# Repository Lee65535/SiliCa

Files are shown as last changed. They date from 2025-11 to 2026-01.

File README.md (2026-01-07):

# SiliCa

`SiliCa` は、JIS X 6319-4（`FeliCa`）互換の非接触型 IC カードです。  
マイコンとして `ATtiny1616` を採用しており、外部電源を必要とせず、カードリーダからの給電によって動作します。

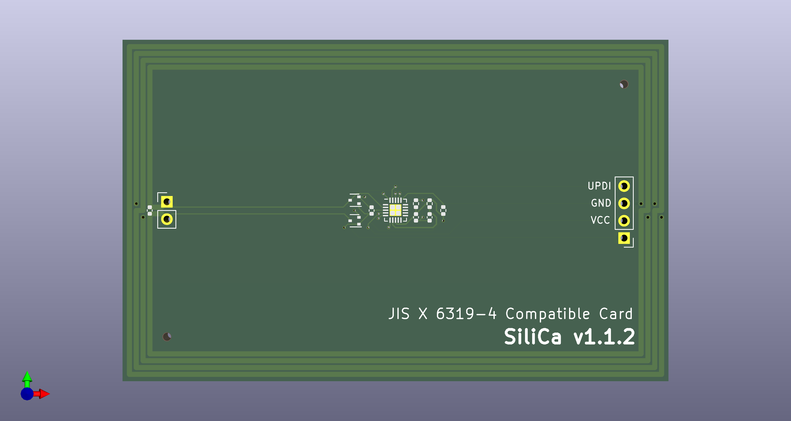
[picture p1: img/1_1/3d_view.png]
3D View


## About This Fork

This fork of SiliCa modifies the firmware so that the device can be used to emulate Amusement IC cards. It will work on bemani games and most bootleg / private servers for SEGA games, but due to technical limitations it is impossible to be used on legit SEGA arcades connected to official servers.

To emulate an Amusement IC, write the IDm as well as data in SPAD_0 to SiliCa, set the system code to 0x88B4, and set service codes to 0x0000 and 0x000B.

## 概要

`SiliCa` は、最小限のハードウェア構成で、 `FeliCa` プロトコルをファームウェアによって再現し、`FeliCa Standard` や `FeliCa Lite-S` のエミュレーションを実現することを目的としています。

また、`SiliCa` では、実際の `FeliCa` カードで書き換えが不可能な `IDm` やシステムコードなどのパラメータを自由に書き換えることができます。

詳細な仕様や使用方法については、寄稿した同人誌 `rand_r(&v3)` をご参照ください。

[技術書典マーケット](https://techbookfest.org/product/an6q3RzcSM0RcWQBevrEM9)
[BOOTH 紙版](https://unset-histfile.booth.pm/items/7650376)
[BOOTH 電子版](https://unset-histfile.booth.pm/items/7650390)

## 回路図

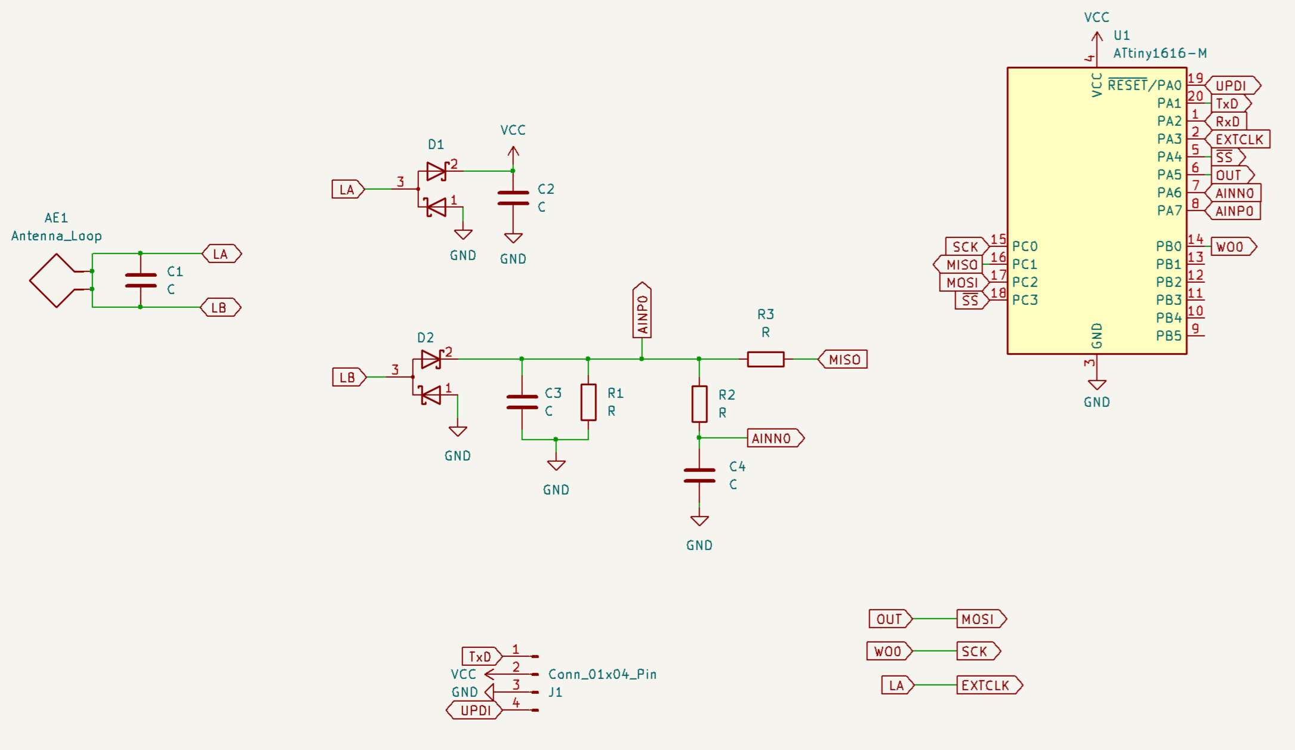
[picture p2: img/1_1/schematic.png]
Schematic


## 注意事項

本プロジェクトは、学術的および実験的な目的で提供されており、商業利用や実際の運用を目的としたものではありません。

---

```
FeliCaは、ソニー株式会社が開発した非接触ICカードの技術方式です。
FeliCaは、ソニーグループ株式会社の登録商標です。
本文では™、®は明記していません。
```

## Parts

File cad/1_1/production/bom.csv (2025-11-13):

Designator | Footprint | Quantity | Value | LCSC Part #
AE1 | PinHeader_1x02_P2.54mm_Vertical | 1 | Antenna_Loop
C1 | 0402 | 4 | C | C1567
C2 | 0402 | 4 | C | C15195
C3 | 0402 | 4 | C | C1523
C4 | 0402 | 4 | C | C1523
D1 | SOT-523 | 2 | D_Schottky_Dual_Series_AKC_Parallel | C2919808
D2 | SOT-523 | 2 | D_Schottky_Dual_Series_AKC_Parallel | C2919808
J1 | PinHeader_1x04_P2.54mm_Vertical | 1 | Conn_01x04_Pin
R1 | 0402 | 3 | R | C11702
R2 | 0402 | 3 | R | C11702
R3 | 0402 | 3 | R | C25123
U1 | VQFN-20-1EP_3x3mm_P0.4mm_EP1.7x1.7mm | 1 | ATtiny1616-M | C507118

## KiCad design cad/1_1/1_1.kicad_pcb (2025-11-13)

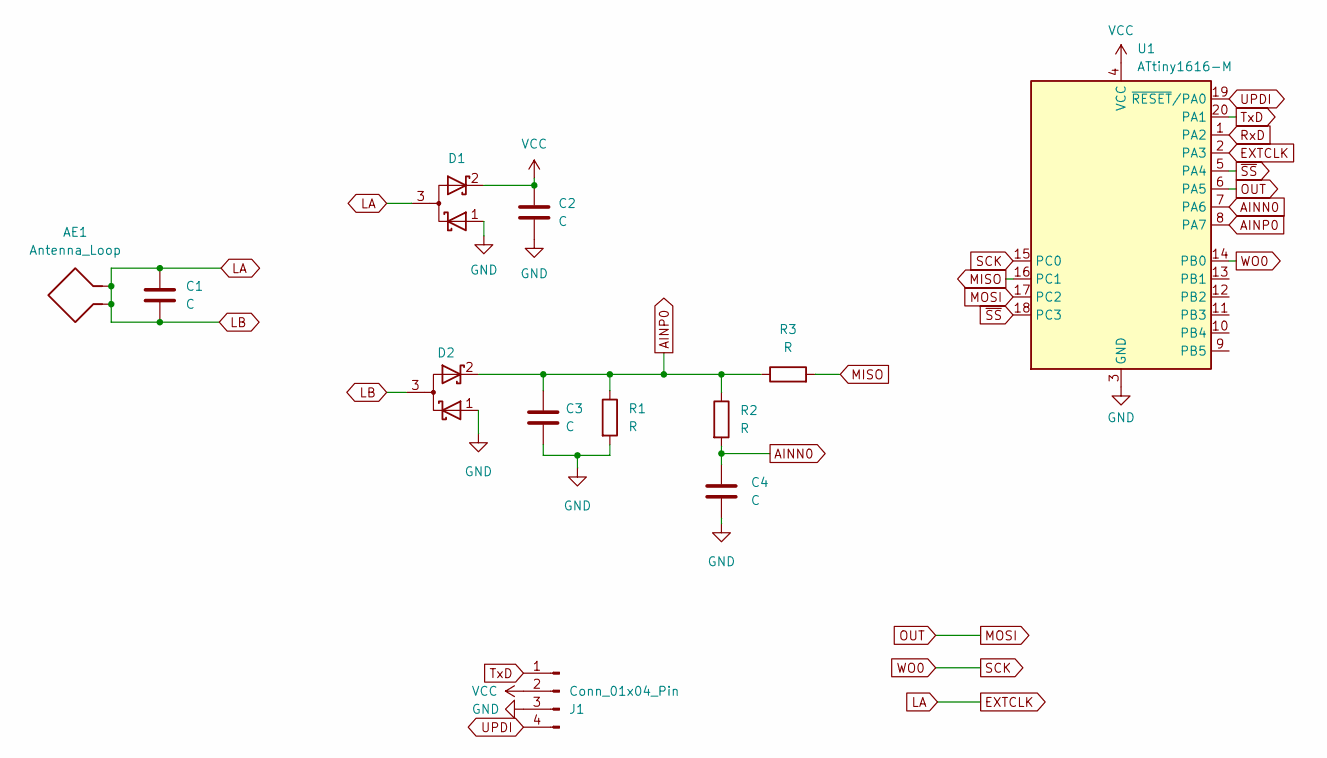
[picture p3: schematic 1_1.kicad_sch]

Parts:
AE1: Antenna_Loop; PinHeader_1x02_P2.54mm_Vertical
C1, C2, C3, C4: C; C_0402_1005Metric
D1, D2: D_Schottky_Dual_Series_AKC_Parallel; SOT-523
J1: Conn_01x04_Pin; PinHeader_1x04_P2.54mm_Vertical
R1, R2, R3: R; R_0402_1005Metric
U1: ATtiny1616-M; VQFN-20-1EP_3x3mm_P0.4mm_EP1.7x1.7mm

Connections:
AINN0: C4.1, R2.2, U1.7 (PA6)
AINP0: C3.1, D2.2 (K), R1.1, R2.1, R3.1, U1.8 (PA7)
EXTCLK: AE1.1, AE1.2, C1.1, C1.2, D1.3 (A), D2.3 (A), U1.2 (PA3)
GND: C2.2, C3.2, C4.2, D1.1 (K), D2.1 (K), J1.3, R1.2, U1.3 (GND), U1.21 (GND)
MISO: R3.2, U1.16 (PC1)
MOSI: U1.6 (PA5), U1.17 (PC2)
RxD: U1.1 (PA2)
SCK: U1.14 (PB0), U1.15 (PC0)
TxD: J1.1, U1.20 (PA1)
UPDI: J1.4, U1.19 (~RESET/PA0)
VCC: C2.1, D1.2 (K), J1.2, U1.4 (VCC)
~SS: U1.5 (PA4), U1.18 (PC3)

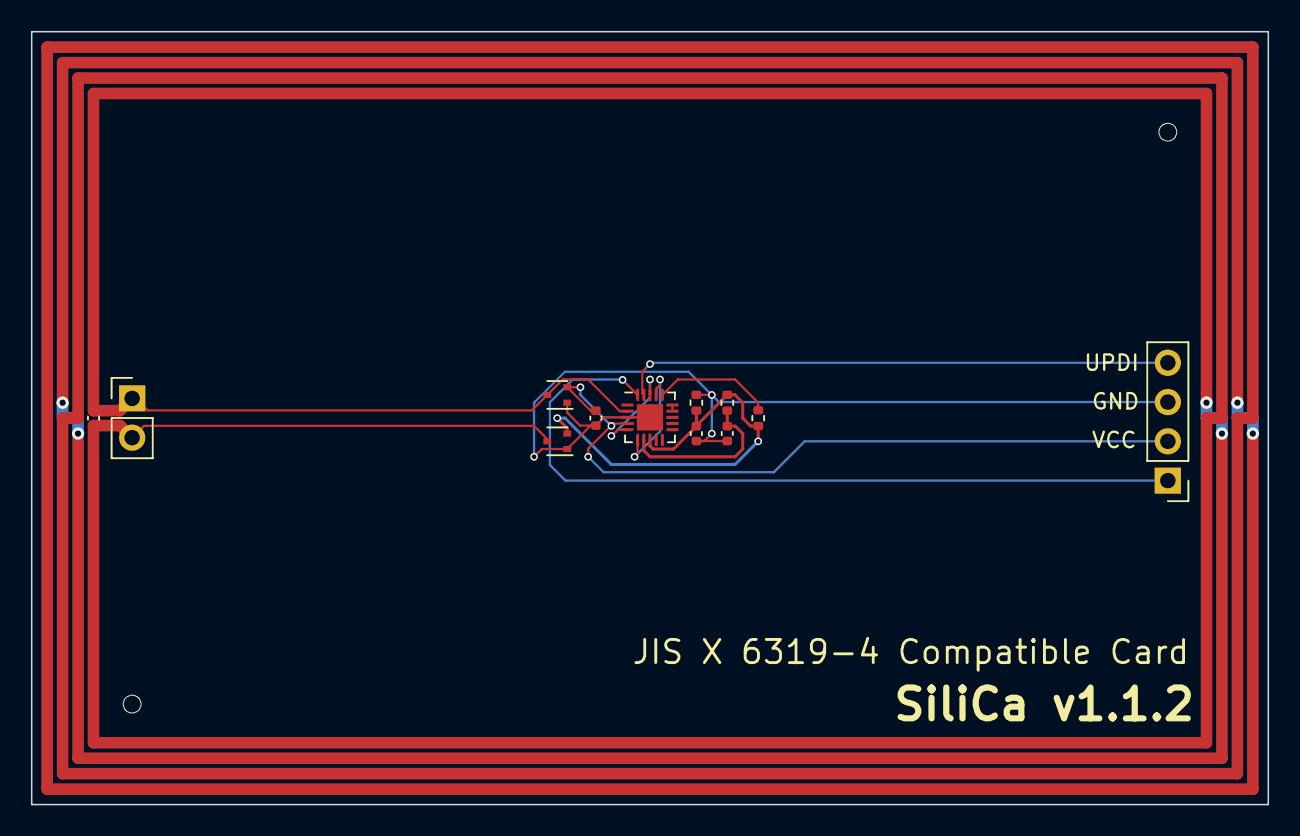
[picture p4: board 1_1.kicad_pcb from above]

Board: 2 copper layers, 80.0 x 50.0 mm, 12 parts (0 on the bottom side), 11 nets.

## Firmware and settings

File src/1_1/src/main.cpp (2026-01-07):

// Implementation of the application layer for
// JIS X 6319-4 compatible card "SiliCa"

#include <stdio.h>
#include <string.h>
#include <avr/eeprom.h>
#include "silica.h"

static constexpr int BLOCK_MAX = 12;
static constexpr int SYSTEM_MAX = 4;
static constexpr int SERVICE_MAX = 4;

constexpr int LAST_ERROR_SIZE = 2;

static uint8_t idm[8];
static uint8_t pmm[8];

static uint8_t EEMEM idm_eep[8];
static uint8_t EEMEM pmm_eep[8];

static uint8_t service_code[2 * SERVICE_MAX];
static uint8_t system_code[2 * SYSTEM_MAX];

static uint8_t EEMEM service_code_eep[2 * SERVICE_MAX];
static uint8_t EEMEM system_code_eep[2 * SYSTEM_MAX];

static uint8_t EEMEM block_data_eep[16 * BLOCK_MAX];

static const int ERROR_BLOCK = 0xE0;
static uint8_t EEMEM last_error_eep[16 * LAST_ERROR_SIZE];

static uint8_t response[0xFF] = {};

void initialize()
{
    // read parameters from EEPROM
    eeprom_read_block(idm, idm_eep, 8);
    eeprom_read_block(pmm, pmm_eep, 8);
    eeprom_read_block(service_code, service_code_eep, 2 * SERVICE_MAX);
    eeprom_read_block(system_code, system_code_eep, 2 * SYSTEM_MAX);
}

bool polling(packet_t command)
{
    // find system code
    int system_index = -1;
    for (int i = 0; i < SYSTEM_MAX; i++)
    {
        uint8_t sc1 = system_code[2 * i];
        uint8_t sc2 = system_code[2 * i + 1];

        if (sc1 == 0 && sc2 == 0)
            break;

        if ((command[2] == sc1 || command[2] == 0xFF) && (command[3] == sc2 || command[3] == 0xFF))
        {
            system_index = i;
            break;
        }
    }

    // avoid bricking cards
    if (command[2] == 0xFF && command[3] == 0xFF)
    {
        system_index = 0;
    }

    if (system_index == -1)
        return false;

    uint8_t request_code = command[4];
    if (request_code == 0x00)
        response[0] = 18;
    else
        response[0] = 20;

    if (request_code > 0x02)
        return false;

    // response code
    response[1] = 0x01;

    // time slot (unused)
    int n = command[5];

    memcpy(response + 2, idm, 8);
    memcpy(response + 10, pmm, 8);

    if (system_index > 0)
    {
        // update the top nibble of IDm with the system index
        response[2] = (system_index << 4) | (response[2] & 0x0F);
    }

    // system code request
    if (request_code == 0x01)
    {
        memcpy(response + 18, system_code + 2 * system_index, 2);
    }
    // communication performance request
    if (request_code == 0x02)
    {
        response[18] = 0x00; // reserved
        response[19] = 0x01; // only 212kbps communication is supported
    }

    return true;
}

bool request_service(packet_t command)
{
    if (command[0] < 11)
        return false;

    // number of nodes
    int n = command[10];
    if (!(1 <= n && n <= 32))
        return false;

    response[0] = 11 + 2 * n;

    response[10] = n;

    // always return key version 0
    for (int i = 0; i < n; i++)
    {
        response[11 + 2 * i] = 0x00;
        response[12 + 2 * i] = 0x00;
    }

    return true;
}

int parse_block_list(int n, const uint8_t *block_list, uint8_t *block_nums)
{
    int j = 0;
    for (int i = 0; i < n; i++)
    {
        if (block_list[j] == 0x80)
        {
            // 2-byte block list element
            block_nums[i] = block_list[j + 1];
            j += 2;
        }
        else if (block_list[j] == 0x00)
        {
            // 3-byte block list element
            if (block_list[j + 2] != 0x00)
                return 0;
            block_nums[i] = block_list[j + 1];
            j += 3;
        }
        else
        {
            return 0;
        }
    }
    // size of block list
    return j;
}

bool read_without_encryption(packet_t command)
{
    // check length
    if (command[0] < 16)
        return false;

    // number of services
    int m = command[10];

    if (m != 1)
    {
        response[0] = 12;    // length
        response[10] = 0xFF; // status flag 1
        response[11] = 0xA1; // status flag 2

        return true;
    }

    uint16_t target_service_code = command[11] | (command[12] << 8);

    // number of blocks
    int n = command[13];

    // find service code
    bool service_found = false;
    for (int i = 0; i < SERVICE_MAX; i++)
    {
        uint16_t sc = service_code[2 * i] | (service_code[2 * i + 1] << 8);
        // if (sc == 0)
        //     continue;

        if (target_service_code == sc)
        {
            service_found = true;
            break;
        }
    }

    if (target_service_code == 0xFFFF)
    {
        service_found = true;
    }

    if (!service_found)
    {
        response[0] = 12;    // length
        response[10] = 0xFF; // status flag 1
        response[11] = 0xA6; // status flag 2

        return true;
    }

    if (!(1 <= n && n <= BLOCK_MAX))
    {
        response[0] = 12;    // length
        response[10] = 0xFF; // status flag 1
        response[11] = 0xA2; // status flag 2

        return true;
    }

    uint8_t block_nums[BLOCK_MAX];
    if (parse_block_list(n, command + 14, block_nums) == 0)
    {
        response[0] = 12;    // length
        response[10] = 0xFF; // status flag 1
        response[11] = 0xA6; // status flag 2
        return true;
    }

    // load block data from EEPROM
    for (int i = 0; i < n; i++)
    {
        int block_num = block_nums[i];

        bool valid_block = false;

        uint8_t *dst = response + 13 + 16 * i;

        if (block_num < BLOCK_MAX)
        {
            valid_block = true;
            eeprom_read_block(dst, block_data_eep + 16 * block_num, 16);
        }
        else if (BLOCK_MAX <= block_num && block_num <= 0xF)
        {
            // we don't have space in EEPROM, so all 0 it is!
            valid_block = true;
            memset(dst, 0x00, 16);
        }
        else if (ERROR_BLOCK <= block_num && block_num < ERROR_BLOCK + LAST_ERROR_SIZE)
        {
            valid_block = true;
            eeprom_read_block(dst, last_error_eep + (block_num - ERROR_BLOCK) * 16, 16);
        }
        else if (0x81 <= block_num && block_num <= 0x92 && block_num != 0x89)
        {
            valid_block = true;
            switch (block_num)
            {
                case 0x81: // MAC
                    memset(dst, 0, 16);
                    break;

                case 0x82: // ID
                    memcpy(dst, idm, 8);
                    // Aime Amusement IC DFC
                    *(dst+8) = 0x00;
                    *(dst+9) = 0x78;
                    memset(dst + 10, 0x00, 6);
                    break;

                case 0x83: // D_ID
                    memcpy(dst, idm, 8);
                    memcpy(dst + 8, pmm, 8);
                    break;

                case 0x84: // SER_C
                    memcpy(dst, service_code, 2 * SERVICE_MAX);
                    memset(dst + 2 * SERVICE_MAX, 0x00, 16 - 2 * SERVICE_MAX);
                    break;

                case 0x85: // SYS_C
                    memcpy(dst, system_code, 2 * SYSTEM_MAX);
                    memset(dst + 2 * SYSTEM_MAX, 0x00, 16 - 2 * SYSTEM_MAX);
                    break;

                case 0x86: // CKV (used in MAC_A authentication)
                case 0x87: // CK
                    memset(dst, 0, 16);
                    break;

                case 0x88: // MC
                    memset(dst, 0xFF, 3); // access permission
                    // Since AIC uses 0x00, we can't make NDEF work :(
                    *(dst + 3) = 0x00; // NDEF compatability
                    *(dst + 4) = 0xFF; // RF parameter
                    memset(dst + 5, 0x00, 11); // memory config
                    break;

                case 0x90: // WCNT (used in MAC_A authentication)
                case 0x91: // MAC_A
                case 0x92: // STATE (used in MAC_A authentication)
                    memset(dst, 0x00, 16);
                    break;                
            }
        }

        if (!valid_block)
        {
            response[0] = 12;    // length
            response[10] = 0xFF; // status flag 1
            response[11] = 0xA8; // status flag 2
            return true;
        }
    }

    response[0] = 13 + 16 * n; // length

    response[10] = 0x00; // status flag 1
    response[11] = 0x00; // status flag 2

    response[12] = n; // number of blocks

    return true;
}

bool write_without_encryption(packet_t command)
{
    int len = command[0];
    int m = command[10]; // number of services
    uint16_t target_service_code = command[11] | (command[12] << 8);
    int n = command[13]; // number of blocks

    if (len < 32)
        return false;

    if (m != 1)
    {
        response[0] = 12;    // length
        response[10] = 0xFF; // status flag 1
        response[11] = 0xA1; // status flag 2

        return true;
    }

    if (!(1 <= n && n <= BLOCK_MAX))
    {
        response[0] = 12;    // length
        response[10] = 0xFF; // status flag 1
        response[11] = 0xA2; // status flag 2
        return true;
    }

    uint8_t block_nums[BLOCK_MAX];
    int N = parse_block_list(n, command + 14, block_nums);

    if (N == 0)
    {
        response[0] = 12;    // length
        response[10] = 0xFF; // status flag 1
        response[11] = 0xA6; // status flag 2
        return true;
    }

    // check length
    if (len != 14 + N + 16 * n)
        return false;

    // write block data to EEPROM
    for (int i = 0; i < n; i++)
    {
        int block_num = block_nums[i];

        bool valid_block = false;

        if (block_num < BLOCK_MAX)
        {
            valid_block = true;
            eeprom_update_block(command + 14 + N + 16 * i, block_data_eep + 16 * block_num, 16);
        }
        
        // On Mutual Authentication (refer to Felica Lite-S User Manual 5.4.2)
        // tl;dr: SEGA game server & card calculate MAC_A based on card-specific shared
        // key and session-specific random challenge; identical result == legit card
        // No replay attacks & copying cards
        // Eavesdropping is possible
        // "Security by Obsecurity"
        
        // In the process, the reader does the following:
        // - Write to RC (0x80)
        // - Read ID, WCNT and MAC_A simultaneously
        // - Write to STATE and MAC_A simultaneously
        // - Read data blocks and MAC_A simultaneously

        // For bootleg servers: The values don't matter at all, just respond anything
        // to these commands.
        // For official servers: Because there is currently no way to acquire the key
        // used in the MAC_A authentication process, SiliCa and similar emulation devices
        // will never work properly on SEGA arcades unless the keys were leaked.

        // RC
        if (block_num == 0x80)
        {
            valid_block = true;
        }

        // D_ID
        if (n == 1 && block_num == 0x83)
        {
            valid_block = true;

            // Update IDm
            memcpy(idm, command + 16, 8);
            eeprom_update_block(idm, idm_eep, 8);

            // Update PMm
            memcpy(pmm, command + 24, 8);
            eeprom_update_block(pmm, pmm_eep, 8);
        }

        // SER_C
        if (n == 1 && block_num == 0x84)
        {
            valid_block = true;

            memcpy(service_code, command + 16, 2 * SERVICE_MAX);
            eeprom_update_block(service_code, service_code_eep, 2 * SERVICE_MAX);
        }

        // SYS_C
        if (n == 1 && block_num == 0x85)
        {
            valid_block = true;

            memcpy(system_code, command + 16, 2 * SYSTEM_MAX);
            eeprom_update_block(system_code, system_code_eep, 2 * SYSTEM_MAX);
        }

        // STATE
        if (block_num == 0x90)
        {
            valid_block = true;
        }

        // MAC_A
        if (block_num == 0x91)
        {
            valid_block = true;
        }

        if (!valid_block)
        {
            response[0] = 12;    // length
            response[10] = 0xFF; // status flag 1
            response[11] = 0xA8; // status flag 2
            return true;
        }
    }

    response[0] = 12; // length

    response[10] = 0x00; // status flag 1
    response[11] = 0x00; // status flag 2

    return true;
}

bool search_service_code(int index)
{
    response[0] = 12;

    if (index < 0 || index >= SERVICE_MAX)
    {
        response[10] = 0xFF;
        response[11] = 0xFF;
        return true;
    }

    uint8_t sc1 = service_code[2 * index];
    uint8_t sc2 = service_code[2 * index + 1];

    if (sc1 == 0x00 && sc2 == 0x00)
    {
        response[10] = 0xFF;
        response[11] = 0xFF;
        return true;
    }

    response[10] = sc1;
    response[11] = sc2;

    return true;
}

bool request_system_code()
{
    int n = 0;

    for (int i = 0; i < SYSTEM_MAX; i++)
    {
        uint8_t sc1 = system_code[2 * i];
        uint8_t sc2 = system_code[2 * i + 1];

        if (sc1 == 0x00 && sc2 == 0x00)
            break;

        response[11 + 2 * i] = sc1;
        response[12 + 2 * i] = sc2;
        n++;
    }

    response[0] = 11 + 2 * n;
    response[10] = n;
    return n != 0;
}

// process application layer command and generate response
packet_t process(packet_t command)
{
    if (command == nullptr)
        return nullptr;

    const int len = command[0];
    const uint8_t command_code = command[1];

    // Polling
    if (command_code == 0x00)
    {
        if (polling(command))
            return response;
        else
            return nullptr;
    }

    // Echo
    if (command[1] == 0xF0 && command[2] == 0x00)
    {
        memcpy(response, command, len);
        return response;
    }

    // verify the tail of IDm matches
    if ((command[2] & 0x0F) != (idm[0] & 0x0F))
        return nullptr;
    if (memcmp(command + 3, idm + 1, 7) != 0)
        return nullptr;

    // check command code
    if (command_code % 2 != 0)
        return nullptr;

    // set response code
    response[1] = command_code + 1;

    // copy IDm from command to response
    memcpy(response + 2, command + 2, 8);

    switch (command_code)
    {
    case 0x02: // Request Service
        if (!request_service(command))
            return nullptr;
        break;
    case 0x04: // Request Response
        if (len != 10)
            return nullptr;

        response[0] = 11;
        response[10] = 0x00;

        break;
    case 0x06: // Read Without Encryption
        if (!read_without_encryption(command))
            return nullptr;
        // status flag 1
        if (response[10] != 0x00)
        {
            save_error(command);
            Serial_println("Read failed");
            print_packet(command);
        }
        break;
    case 0x08: // Write Without Encryption
        if (!write_without_encryption(command))
            return nullptr;
        break;
    case 0x0A: // Search Service Code
    {
        // Define in switch is prohibited in C++
        // use a block here
        if (len != 12)
            return nullptr;

        int index = command[10] | (command[11] << 8);
        search_service_code(index);
    }
    break;
    case 0x0C: // Request System Code
        if (len != 10)
            return nullptr;
        if (!request_system_code())
            return nullptr;
        break;
    case 0x10: // Authentication1
    // pass through for unsupported commands
    default:
        return nullptr;
    }

    return response;
}

void save_error(packet_t command)
{
    int len = command[0];
    if (len > sizeof(last_error_eep))
        len = sizeof(last_error_eep);

    eeprom_update_block(command, last_error_eep, len);
}

// Debug: print packet to serial
void print_packet(packet_t packet)
{
    int len = packet[0];
    if (len == 0)
    {
        Serial_println("<empty>");
        return;
    }

    for (int i = 1; i < len; i++)
    {
        char hex_str[5];
        sprintf(hex_str, "%02X", packet[i]);
        Serial_print(hex_str);
        if (i != len - 1)
            Serial_print(" ");
    }
    Serial_println("");
}

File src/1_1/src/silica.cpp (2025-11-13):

// Implementation of the physical and data link layers for
// JIS X 6319-4 compatible card "SiliCa"

#include <stdio.h>
#include <stdint.h>
#include <string.h>
#include <avr/io.h>
#include <util/crc16.h>
#include <util/delay.h>
#include "silica.h"

// data link layer header
static const uint8_t header[] = {0x00, 0x00, 0x00, 0x00, 0x00, 0x00, 0xB2, 0x4D};

// buffer for receiving data and command processing
static uint8_t rx_buf[0x220] = {};
static uint8_t command[0x110] = {};

// Functions for serial output.
// These functions perform blocking writes.
void Serial_write(uint8_t data)
{
    while (!(USART0.STATUS & USART_DREIF_bm))
    {
        // do nothing
    }
    USART0.TXDATAL = data;
}

void Serial_print(const char *str)
{
    while (*str)
        Serial_write(*str++);
}

void Serial_println(const char *str)
{
    Serial_print(str);
    Serial_print("\r\n");
}

// transfer one byte via SPI
// Arduino SPI.transfer() equivalent
uint8_t SPI_transfer(uint8_t data = 0)
{
    while (!(SPI0.INTFLAGS & SPI_DREIF_bm))
    {
        // do nothing
    }
    SPI0.DATA = data;
    return SPI0.DATA;
}

// calculate CRC16-CCITT
uint16_t crc16(const uint8_t *buf, int len)
{
    uint16_t crc = 0;
    for (int i = 0; i < len; i++)
        crc = _crc_xmodem_update(crc, buf[i]);
    return crc;
}

// capture frame from SPI
// return length of captured data
int capture_frame()
{
    // wait for start of frame
    for (int i = 0; i < sizeof(rx_buf); i++)
    {
        uint8_t data = SPI_transfer();
        rx_buf[i] = data;

        // end of frame
        if (data == 0x00 || data == 0xFF)
        {
            // frame too short
            if (i < sizeof(header) * 2)
            {
                i = -1;
                continue;
            }
            else
            {
                return i + 1;
            }
        }
    }
    // frame too long
    return 0;
}

// Debug: print captured frame to serial
void print_frame(int rx_len)
{
    for (int i = 0; i < rx_len; i++)
    {
        char hex_str[5];
        sprintf(hex_str, "%02X", rx_buf[i]);
        Serial_print(hex_str);
        if (i != rx_len - 1)
            Serial_print(" ");
    }
    Serial_println("");
}

// determine bit shift from sync pattern
// return -1 if not a valid sync pattern
int get_shift_from_sync(uint8_t sync1, uint8_t sync2)
{
    uint8_t a1 = sync1 & 0xAA;
    uint8_t b1 = sync1 & 0x55;

    uint8_t a2 = sync2 & 0xAA;
    uint8_t b2 = sync2 & 0x55;

    if (a1 == 0x8A && a2 == 0x08)
        return 0;
    if (b1 == 0x45 && b2 == 0x04)
        return 1;
    if (a1 == 0x22 && a2 == 0x82)
        return 2;
    if (b1 == 0x11 && b2 == 0x41)
        return 3;
    if (a1 == 0x08 && a2 == 0xA0)
        return 4;
    if (b1 == 0x04 && b2 == 0x50)
        return 5;
    if (a1 == 0x02 && a2 == 0x28)
        return 6;
    if (b1 == 0x01 && b2 == 0x14)
        return 7;

    return -1;
}

// find sync pattern in received data
// return index of first sync byte
int find_sync_index(int rx_len, int &shift, bool &invert)
{
    for (int i = 0; i < rx_len - 1; i++)
    {
        int shift1 = get_shift_from_sync(rx_buf[i], rx_buf[i + 1]);
        int shift2 = get_shift_from_sync(~rx_buf[i], ~rx_buf[i + 1]);
        if (shift1 != -1 && shift1 > shift2)
        {
            shift = shift1;
            invert = false;
            return i;
        }
        if (shift2 != -1 && shift2 > shift1)
        {
            shift = shift2;
            invert = true;
            return i;
        }
    }
    return -1;
}

// extract one byte from 3 bytes of received data
// according to the specified bit shift
uint8_t extract_byte(int shift, uint8_t data1, uint8_t data2, uint8_t data3)
{
    uint8_t x = 0;
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

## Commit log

2025-11-13 v1.1 (#1)
    [1_1.kicad_pcb, 1_1.kicad_sch, bom.csv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]
2025-11-17 BOOTHリンク追加
